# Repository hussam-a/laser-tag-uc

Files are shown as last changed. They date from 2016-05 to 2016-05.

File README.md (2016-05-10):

# laser-tag-uc
Microcontroller-based Laser Tag system

Authors:

Hussam A. El-Araby (github.com/hussam-a)

Mostafa Konsowa (github.com/konsowa)

Youssef Gaber (github.com/Gabrola)

Mennatallah Yahia

Ziad Osama

Project code and configurations are under the GNU GPL license (laser-tag-uc/LICENSE) 

# Project structure:

- Check files under folder project (laser-tag-uc/project)

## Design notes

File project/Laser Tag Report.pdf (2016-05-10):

# Laser Tag Game System: A Microcontroller-based Design

### Design and Implementation of a simple Laser Tag game system using microcontrollers that communicate with each other through laser and with a

central computer server through Wifi.

### Hussam Ashraf El-Araby Menna Yehia Mostafa Konsowa Youssef Gaber Ziad Osama

### 20th December 2015

Project Overview:
What is Laser Tag?
Laser Tag components:
Functional Requirements:
Non-functional Requirements: Market Value:
Hardware Design:
Player Unit Block Diagram
Server Block Diagram
System components communication: Microcontroller Ports:
Software Design:
System tasks:
Implementation:
Hardware Design Notes, Problems and Changes: Software Implementation:
Software Design Notes, Problems and Changes: Implemented Functional Requirements
Future Improvements:
Appendix A (Code):
Appendix B (Hardware Design):
Laser Tag Schematic Design Laser Tag Board Design
Laser Tag Bill of Materials

### Project Overview:

The following report is about our semester project for the course “Microcontroller-based System Design” with Dr. Shaalan during Fall 2015. We designed and implemented a laser tag game system. It is based on a set of microcontrollers and a central game server.

Note: Any attached pictures or files are also available in their original formats in the submission folder containing this report.

### What is Laser Tag?

Laser tag is a team or individual sport or recreational activity where players attempt to score points by tagging targets, typically with a hand-held infrared-emitting targeting device. Infrared-sensitive targets are commonly worn by each player and are sometimes integrated within the arena in which the game is played (Wikipedia).

Usually, a central server/entity exists that collects information about the game status, deaths, kills, and other game related information. However, some arenas lack a central entity and need to collect the player units after the game to calculate the scores.

In our project , we have a central computer server and several player units. The player units are microcontroller based and represent the laser shooting element (weapon) and the laser sensing element (vest). The score calculation element is the central game server (wifi connected computer).

### Laser Tag components:

Hardware view:

1. Player units: Microcontroller + LCD + Laser Sensing Element + Laser Emitting Element + Wifi
2. Central game server: Computer + Wifi
Logical view:
1. Weapon
2. Vest
3. Player LCD
4. Scoreboard and configuration server

### Functional Requirements:

The functional requirements are divided by system component (logical view)

1) Weapon:
a) Weapon shoots bullets with information about the damage the bullet incurs and the information about the shooter.
b) Weapon has current bullet count, maximum ammo, and number of magazines.
c) Weapon has shoot button, reload button and change weapon button.
d) Weapon is upgradable (according game mechanics).
2) Vest:
a) Vest senses if shot and by whom and then automatically deducts the bullet damage from health.

b) Vest detects if player is killed by bullet (health reaches zero) and by whom.
c) Vest keeps track of current health value as well as setting a maximum health value.
d) Vest contains an LED to show other players whether the player is dead or alive.
3) Player LCD:
a) LCD shows different information about weapon (as stated above)
b) LCD shows different information about health (as stated above)
4) Scoreboard and Configuration Server:
a) Scoreboard shows ranks, kills, death, and other statistics about all the players.
b) Configuration server sets game mode (Free for all vs teams)
c) Configuration server creates matches associating different players with a match being played.
d) Configuration server initializes weapons, scoreboard, and other related items at start of the match.
e) Configuration server has direct access to weapon and vest, used to upgrade the weapons, and other miscellaneous actions.
f) Configuration server ends the matches and shows final results.

### Non-functional Requirements:

### 1. Responsiveness and High Performance

a. Response times should be small to the degree the game appears instant to humans
i. Some processing can be done locally on the player unit instead of sending it to server, hence improving overall performance (less communications).

### 2. Reliability

a. Any data exchanged with the server should be verified as correct using mechanisms such as CRC.
b. Laser should be detected reliably at the specified maximum distance.
c. Ambient light should not interfere with the laser detection.
d. The game system should not loose information during the matches and the scoreboard should reflect the true performance of the players.

### 3. Scalability

a. The system should be able to handle the maximum amount of players without any apparent performance issues.
b. The server should be able to handle multiple concurrent matches if needed.

### 4. Safety

a. The laser used should not significantly harm any of the players or spectators, if accidently shined into their eyes.

### Market Value:

Laser tag is a fun game for people of a wide variety of different age groups. It would appeal to many Egyptians looking for alternative activities to do. The product, manufactured locally, would be of interest to many business owners, looking to run such an activity, but are overwhelmed by the costs of purchasing expensive equipment and building an arena. High-end laser tag equipment can cost as much as $61,800 for only 16 vests which is an extremely high price for business owners in Egypt (http://www.laser-tron.com/index.php/products/pricing-and-financing-options).

### Hardware Design:

The player unit required hardware design. Our hardware design goal was to minimise cost and yet be able to achieve the requirements.

The circuit schematic and PCD board design of the player unit are attached in the end of this document in Appendix B.

The following diagrams describe the architecture of the system.

### Player Unit Block Diagram

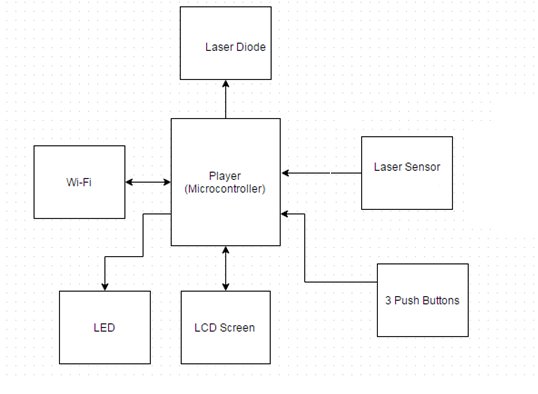
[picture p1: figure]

### Server Block Diagram

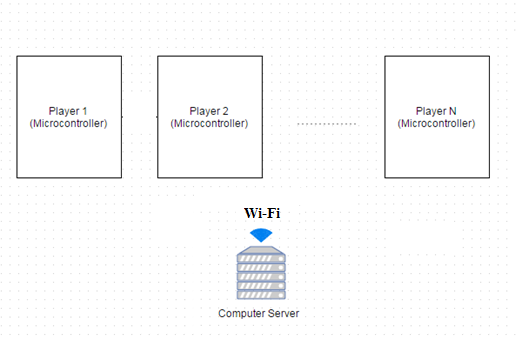
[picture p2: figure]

### System components communication:

Two communication channels exist within the system.

Player ⇔ Server

Player ⇔ Player

Player ⇔ Server Communication Protocol:

Player equipment and the server will communicate over TCP/IP.

### Microcontroller Ports:

- Laser TX: 1 I/O Pin
- Laser Sensor RX: 1 I/O Pin
- LCD Screen: 8 Data Pins, 4 Control Pins
- WiFi: 4 SPI Pins + 1 Enable Pin + 1 Interrupt Pin
- LED: 1 I/0 Pin
- 3 Buttons: 3 I/0 Pins
- Minimum I/O Pins: 24 pins

### Software Design:

The system is mainly an interrupt driven application.

### System tasks:

### 1. Gun:

N | Task | Periodic/Aperiodic | Notes
1 · The fire button is pressed · Check if player has enough ammo. · If yes: · If no: | Trigger: Action: · Sends data (player ID + bullet damage) to UART to be sent as laser pulses to hit the target · Decrease the ammo by one. · Communicate ammo change to server. (task below) · Update LCD with ammo change (task below) · Do nothing. | Aperiodic
2 · The reload button is pressed · Check if player has enough ammo. · If yes: · If no: | Trigger: Action: · Reload the ammo. · Communicate ammo change to server. (task below) · Update LCD with ammo change (task below) · Do nothing. | Aperiodic
3 · The switch weapon button is pressed · Switch to another weapon · Communicate ammo change to server (task · Update LCD with weapon change (task | Trigger: Action: below) | Aperiodic

| below)
4 · Data has been placed in UART transfer · Interrupt the TX port of the UART | Trigger: register, to be sent as laser pulses. Action: · When data signal is 0, disable the PWM. · When data signal is 1, enable the PWM | Aperiodic | PWM to be initialized to have a duty cycle of 50%. It is enabled or disabled according to data signal

### 2. Vest

| Task | Periodic/Aperiodic | Notes
1 · Laser sensor continuously receives data (light) · Demodulation of data is needed before | Description: passing the data to RX port of microcontroller | Periodic, 10KHz | Task of highest priority
2 · Decrement the health, according to bullet · Communicate health change to server (task · Update LCD with health change (task below) · If player is dead: | Trigger: Bullet information resulting from data demodulation Action: damage info. below) · Turn off their LED on their vest · Communicate who killed player to server (task below) | Aperiodic

### 3. Player LCD

1 Trigger: · Information to display on LCD changed Action: · Display is updated

Aperiodic

### 4. Server Communication

Task | Periodic/Aperiodic | Notes

1 · Server receives request from player to send · After establishing connection, server · Server has array of players, each player is a · Server updates scoreboard / other | Trigger: data to server. Action: receives data from one player and identify the player through player ID class which has private data members corresponding to the state of the player (health, weapon, ammo, score, …etc) information. | Aperiodic, happens when server receives request
2 · Server requests connection to send data · After establishing connection, server send · Player unit updates itself using this data. | Trigger: to player for example weapon upgrade Action: data to one player and identify the player through player ID | Aperiodic, happens when server send request

### Implementation:

We implemented the most important subset of the requirements for a demonstration on December 15th, 2015 (more details later on the implemented subset).
The implementation code is in Appendix A.

### Hardware Design Notes, Problems and Changes:

One main problem that faced us while designing the hardware was the choice of the laser emitting and laser sensing elements.

The laser emitting element was hard to find because we wanted to find one that:
1. Worked on 3.3V-5V.
2. Could be controlled digitally (on/off modes only).
3. Emitted a powerful enough laser to be sensed from a reasonable distance.

The laser sensing element was hard to find because:
1. Most of the light sensors on the market worked with infrared not visible light laser.
a. So it was difficult to choose both emitter and sensor of compatible frequencies.

Also it is useful to note that we implemented the project using a very small sensor. This does not reflect reality where the vest is actually has a very large surface area, but that is what we obtained to work with. Using a real vest later will require changes in the hardware design, but we assume the software would remain almost the same.

### Software Implementation:

Our implementation is based on a set of classes to manage the scoreboard, beside establishing connections with more than one player and receiving and sending packets from and to each player. We have class Player to model each player with ID, health, ammos, shots, deaths, hits, status(alive or not). We also have classes GameServerHandler inheriting from IServerHandler, class AshynchronousServer and Packet to manage establishing connection and desterilizing data from packet.
We begin by instantiating objects from GameServerHandler and AsynchronousServer classer, the object of the latter class keeps listening on a predefined port until it receives a request for connection. The server then continuously call showStatistics() and doAction() methods in Round Robin fashion.

The showStatistics() method sorts the list of players according to their score, and displays for each player Player ID, alive/dead, Kills, Deaths, Kills/Deaths Ratio, Hit Ratio, Shots, Health.

The doAction() method executes the required action depending on the status of the player (dead/alive).
We also have class BasicClient to manage client code of sending packets to the server.

### Software Design Notes, Problems and Changes:

To achieve reliability of laser sensing we intended to modulate the laser information sent by the sending end and later demodulate it at the receiving end.

Modulation/Demodulation process

The modulation/demodulation process is explained more here (http://www.schoolphysics.co.uk/age14-16/Wave%20properties/text/Modulation_and_demodulation/index.html). (http://www.schoolphysics.co.uk/age14-16/Wave%20properties/text/Modulation_and_demodulation/index.html)

Modulating the information sent (lower frequency) on a carrier signal (higher frequency) helps avoid the interference of ambient light (noise) with the laser signal.

The problem resides in the fact that the demodulation should occur all the time. The sensor cannot tell without demodulation the light entering it if a valid laser signal was sent and the contents of that signal.

The demodulation algorithm did not work on the microcontroller as we were not able to implement it sequentially within the code. It consumes most CPU cycles, blocking all the other tasks on the player unit.

It needed a separate parallel circuit, one which an FPGA can provide.

We also tried looking for hardware demodulation but due to lack of the required ICs, we just resorted to not modulating the laser signal. This affected the reliability significantly and the demonstration needed to work away from bright lights that will cause noise.

Moreover, we changed from an interrupt driven application to a round robin - state machine hybrid application. The reason for that was that we did not find that the application’s performance would suffer using the round robin method as the human reaction time covers for any delays and would not become apparent. Advantage that round robin - state machine hybrid is a simpler implementation.

### Implemented Functional Requirements

Due to limited time and pressure from the courses and upcoming finals we chose a subset to implement of the functional requirements. (check table below)

We chose the subset to showcase the most important parts of the system:
1. Component Communications (Player - Player and Player- Server)
2. Crucial Game Mechanics (Firing, Reloading, Kills, Deaths, and Scoring)

Regarding non-functional requirements, we assumed we achieved them to a sufficient level. Except for reliability due to the ambient light problem (explained above). Moreover, validating the non-functional requirements would require a larger deployment of the system and more real life use by game testers. All this was not available to us, cost wise or time wise.

Note: The index is the same as one written previously in functional requirements section.

Functional Requirement Index | Implemented? | Notes
1a | Partial | Bullet damage was not implemented, all bullets same damage.
1b | Yes
1c | Partial | Change weapon button was not implemented, as we did not do primary/secondary weapons
1d | No
2a | Partial | Related to 1a note. No specific bullet damages
2b | Yes
2c | Yes
2d | No
3a | Yes
3b | Yes
4a | Yes
4b | Partial | We only implemented a free for all mode.
4c | Yes
4d | Yes
4e | Partial | The server has the ability to initialize the players but a true direct access to all the player’s weapon and vest information is missing.
4f | Yes

### Future Improvements:

Many parts of the project may be improved.

Such as:

1. Implementing the partially and not implemented functional requirements.
2. Merge the laser emitting code with the laser sensing code (ie. unify the player unit code).
3. More deployment and testing to assert that non-functional requirements are achieved.
4. Refactor the code to make it more extensible rather than hard coded.
5. Re-evaluate whether round robin - state machine hybrid used is sufficient or is there a better method.

### Appendix A (Code):

Note: Refer to the files included in the submission.

Explanation of code arrangement:

Inside the “Demo Code” folder:

- “BasicServer” folder
- C# code that implements the game server and server functions.
- Classes used, include:
■ Event Type: class to describe all the possible game events ■ Packet: class to describe the packet sent/received
■ Player: class to describe the player
■ Other classes and functions.
- “Laser” folder
- C code that implements the laser emitting functions.
- “Sensor” folder
- C code that implements the laser sensing functions.

### Appendix B (Hardware Design):

Attached below is:

1. Eagle Schematic Design (.sch)
2. Eagle Board Design (.brd)
3. Bill of Material (BOM) (.xlsx)

### Laser Tag Schematic Design

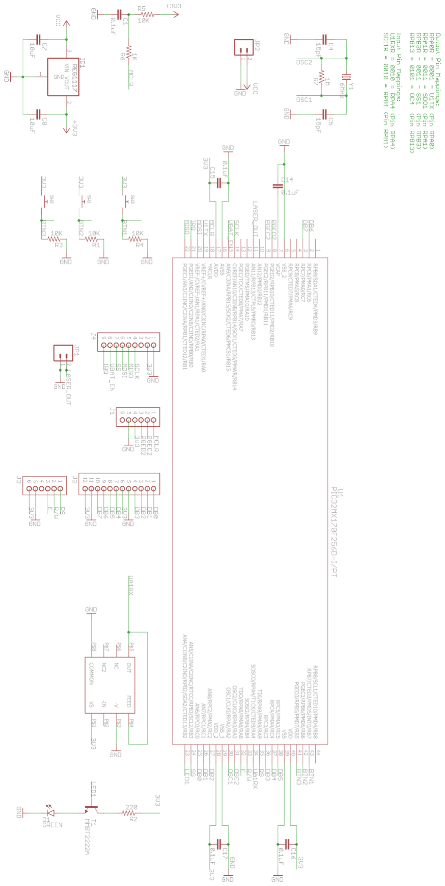
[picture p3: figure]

### Laser Tag Board Design

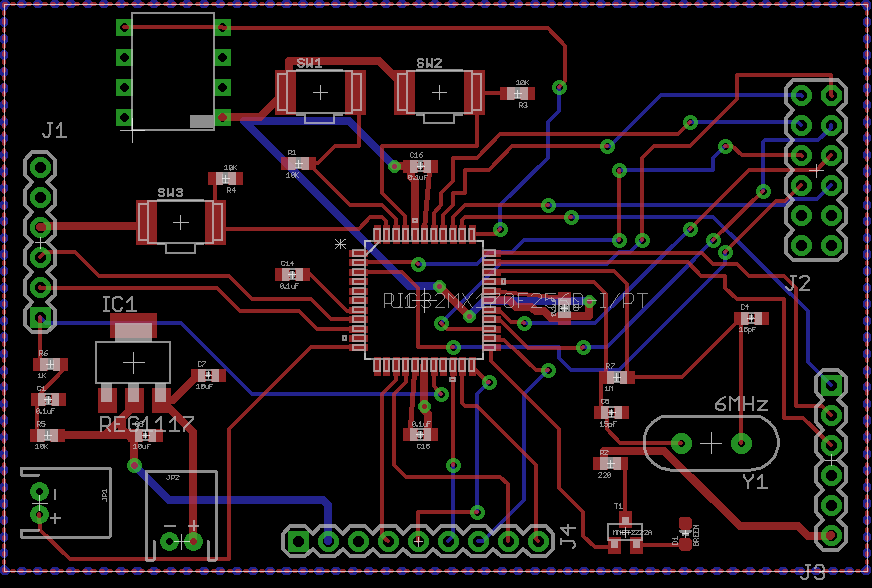
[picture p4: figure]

### Laser Tag Bill of Materials

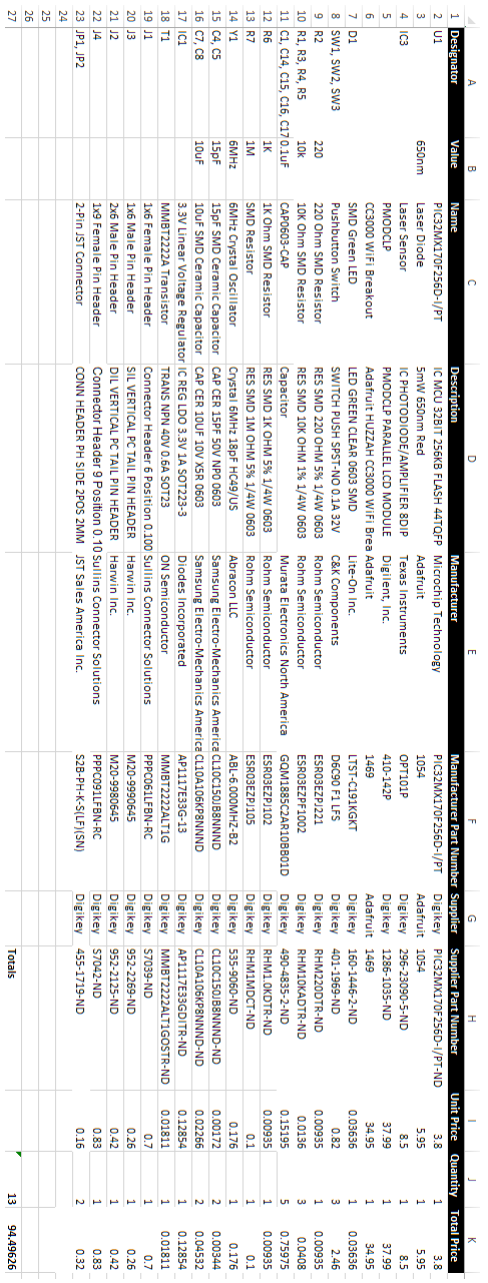
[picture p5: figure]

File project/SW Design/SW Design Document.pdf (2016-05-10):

# Microcontrollers-based system design

# S/W Design Document

# Laser Tag Project

Dr. Mohamed Shalan

4/12/2015

### Hussam El-Araby Menna Yahia Mostafa Konsowa Youssef Gaber Ziad Osama

### System components:

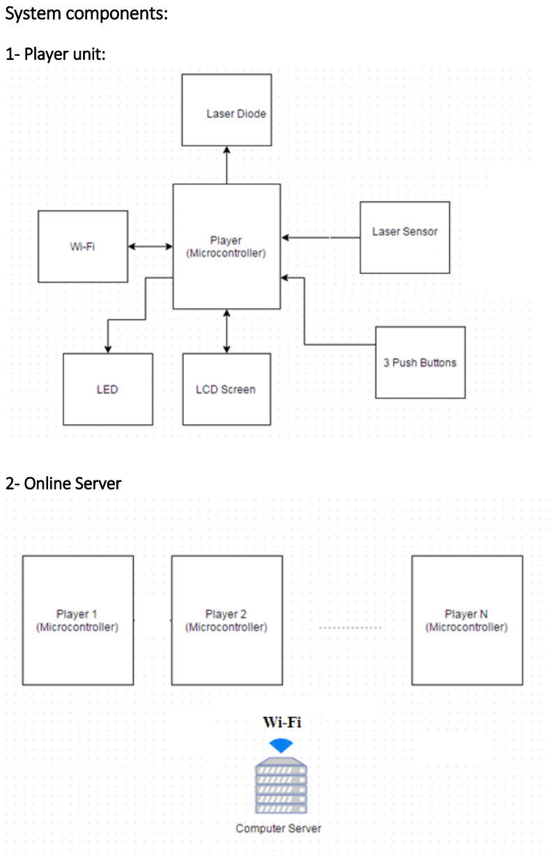
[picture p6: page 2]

### 1- Player unit:

### 2- Online Server

### Two types of communication exist in the system:

### Player – Server:

### Player – Player:

### Overview of system tasks:

### 1. Gun:

N | Task | Periodic/Aperiodic | Notes
1 | Trigger: • The fire button is pressed Action: • Check if player has enough ammo. • If yes: • Sends data (player ID + bullet damage) to UART to be sent as laser pulses to hit the target • Decrease the ammo by one. • Communicate ammo change to server. (task below) • Update LCD with ammo change (task below) • If no: • Do nothing. | Aperiodic
2 | Trigger: • The reload button is pressed Action: • Check if player has enough ammo. • If yes: • Reload the ammo. • Communicate ammo change to server. (task below) • Update LCD with ammo change (task below) • If no: • Do nothing. | Aperiodic
3 | Trigger: • The switch weapon button is pressed Action: • Switch to another weapon • Communicate ammo change to server (task below) • Update LCD with weapon change (task below) | Aperiodic
4 | Trigger: • Data has been placed in UART transfer register, to be sent as laser pulses. Action: • Interrupt the TX port of the UART | Aperiodic | PWM to be initialized to have a duty cycle of 50%. It is enabled or disabled according to data signal

- When data signal is 0, disable the PWM.
- When data signal is 1, enable the PWM

### 2. Vest

| Task | Periodic/Aperiodic | Notes
1 | Description: • Laser sensor continuously receives data (light) • Demodulation of data is needed before passing the data to RX port of microcontroller | Periodic, 10KHz | Task of highest priority
2 | Trigger: Bullet information resulting from data demodulation Action: • Decrement the health, according to bullet damage info. • Communicate health change to server (task below) • Update LCD with health change (task below) • If player is dead: • Turn off their LED on their vest • Communicate who killed player to server (task below) | Aperiodic

### 3. LCD

1 Trigger: • Information to display on LCD is changed Action: • Display is changed

Aperiodic

### 4. Server Communication

| Task | Periodic/Aperiodic | Notes
1 | Trigger: • Server receives request from player to send data to server. Action: • After establishing connection, server receives data from one player and identify the player through player ID • Server has array of players, each player is a class which has private data members | Aperiodic, happens when server receives request

| corresponding to the state of the player (health, weapon, ammo, score, …etc) • Server updates scoreboard / other information.
2 | Trigger: • Server requests connection to send data to player for example weapon upgrade Action: • After establishing connection, server send data to one player and identify the player through player ID • Player unit updates itself using this data. | Aperiodic, happens when server send request

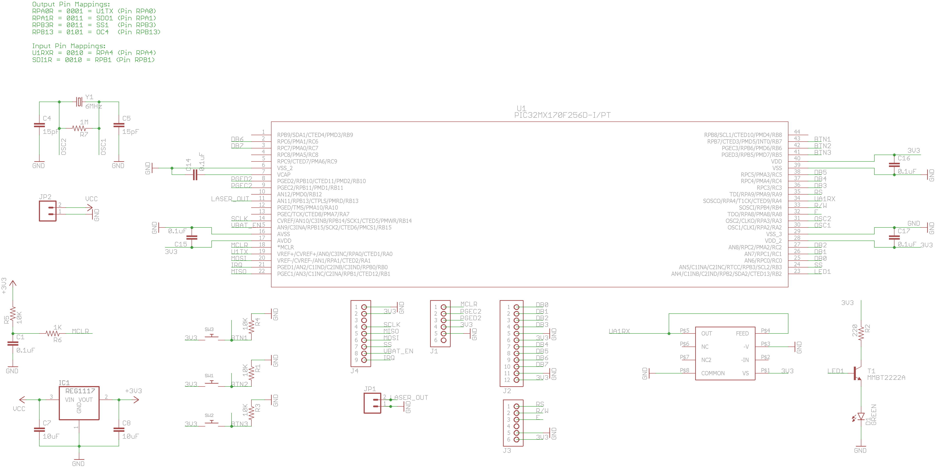
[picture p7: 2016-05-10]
project/Report Attachments/Laser Tag Schematic.png

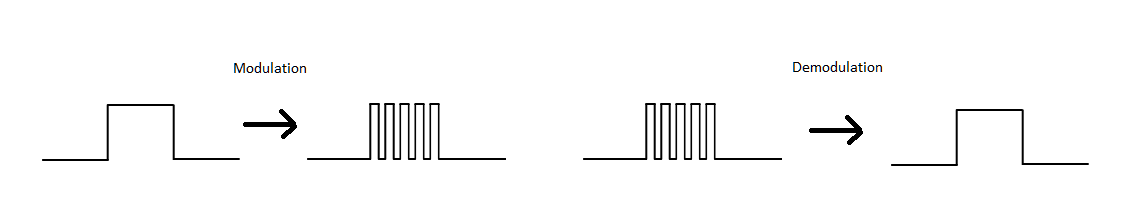
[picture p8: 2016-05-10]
project/Report Attachments/mod_demod.png

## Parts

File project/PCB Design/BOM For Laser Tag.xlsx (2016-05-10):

Designator | Value | Name | Description | Manufacturer | Manufacturer Part Number | Supplier | Supplier Part Number | Unit Price | Quantity | Total Price
U1 |  | PIC32MX170F256D-I/PT | IC MCU 32BIT 256KB FLASH 44TQFP | Microchip Technology | PIC32MX170F256D-I/PT | Digikey | PIC32MX170F256D-I/PT-ND | 3.8 | 1 | 3.8
 | 650nm | Laser Diode | 5mW 650nm Red | Adafruit | 1054 | Adafruit | 1054 | 5.95 | 1 | 5.95
IC3 |  | Laser Sensor | IC PHOTODIODE/AMPLIFIER 8DIP | Texas Instruments | OPT101P | Digikey | 296-23090-5-ND | 8.5 | 1 | 8.5
 |  | PMODCLP | PMODCLP PARALLEL LCD MODULE | Digilent, Inc. | 410-142P | Digikey | 1286-1035-ND | 37.99 | 1 | 37.99
 |  | CC3000 WiFi Breakout | Adafruit HUZZAH CC3000 WiFi Breakout | Adafruit | 1469 | Adafruit | 1469 | 34.95 | 1 | 34.95
D1 |  | SMD Green LED | LED GREEN CLEAR 0603 SMD | Lite-On Inc. | LTST-C191KGKT | Digikey | 160-1446-2-ND | 0.03636 | 1 | 0.03636
SW1, SW2, SW3 |  | Pushbutton Switch | SWITCH PUSH SPST-NO 0.1A 32V | C&K Components | D6C90 F1 LFS | Digikey | 401-1969-ND | 0.82 | 3 | 2.46
R2 | 220 | 220 Ohm SMD Resistor | RES SMD 220 OHM 5% 1/4W 0603 | Rohm Semiconductor | ESR03EZPJ221 | Digikey | RHM220DTR-ND | 0.00935 | 1 | 0.00935
R1, R3, R4, R5 | 10k | 10K Ohm SMD Resistor | RES SMD 10K OHM 1% 1/4W 0603 | Rohm Semiconductor | ESR03EZPF1002 | Digikey | RHM10KADTR-ND | 0.0136 | 3 | 0.0408
C1, C14, C15, C16, C17 | 0.1uF | CAP0603-CAP | Capacitor | Murata Electronics North America | GQM1885C2AR10BB01D | Digikey | 490-4835-2-ND | 0.15195 | 5 | 0.75975
R6 | 1K | 1K Ohm SMD Resistor | RES SMD 1K OHM 5% 1/4W 0603 | Rohm Semiconductor | ESR03EZPJ102 | Digikey | RHM1.0KDTR-ND | 0.00935 | 1 | 0.00935
R7 | 1M | SMD Resistor | RES SMD 1M OHM 5% 1/4W 0603 | Rohm Semiconductor | ESR03EZPJ105 | Digikey | RHM1MDCT-ND | 0.1 | 1 | 0.1
Y1 | 6MHz | 6MHz Crystal Oscillator | Crystal 6MHz 18pF HC49/US | Abracon LLC | ABL-6.000MHZ-B2 | Digikey | 535-9060-ND | 0.176 | 1 | 0.176
C4, C5 | 15pF | 15pF SMD Ceramic Capacitor | CAP CER 15PF 50V NP0 0603 | Samsung Electro-Mechanics America, Inc. | CL10C150JB8NNND | Digikey | CL10C150JB8NNND-ND | 0.00172 | 2 | 0.00344
C7, C8 | 10uF | 10uF SMD Ceramic Capacitor | CAP CER 10UF 10V X5R 0603 | Samsung Electro-Mechanics America, Inc. | CL10A106KP8NNND | Digikey | CL10A106KP8NNND-ND | 0.02266 | 2 | 0.04532
IC1 |  | 3.3V Linear Voltage Regulator | IC REG LDO 3.3V 1A SOT223-3 | Diodes Incorporated | AP1117E33G-13 | Digikey | AP1117E33GDITR-ND | 0.12854 | 1 | 0.12854
T1 |  | MMBT2222A Transistor | TRANS NPN 40V 0.6A SOT23 | ON Semiconductor | MMBT2222ALT1G | Digikey | MMBT2222ALT1GOSTR-ND | 0.01811 | 1 | 0.01811
J1 |  | 1x6 Female Pin Header | Connector Header 6 Position 0.100" | Sullins Connector Solutions | PPPC061LFBN-RC | Digikey | S7039-ND | 0.7 | 1 | 0.7
J3 |  | 1x6 Male Pin Header | SIL VERTICAL PC TAIL PIN HEADER | Harwin Inc. | M20-9990645 | Digikey | 952-2269-ND | 0.26 | 1 | 0.26
J2 |  | 2x6 Male Pin Header | DIL VERTICAL PC TAIL PIN HEADER | Harwin Inc. | M20-9980645 | Digikey | 952-2125-ND | 0.42 | 1 | 0.42
J4 |  | 1x9 Female Pin Header | Connector Header 9 Position 0.100" | Sullins Connector Solutions | PPPC091LFBN-RC | Digikey | S7042-ND | 0.83 | 1 | 0.83
JP1, JP2 |  | 2-Pin JST Connector | CONN HEADER PH SIDE 2POS 2MM | JST Sales America Inc. | S2B-PH-K-S(LF)(SN) | Digikey | 455-1719-ND | 0.16 | 2 | 0.32
 |  |  |  |  |  |  | Totals |  | 13 | 94.49626

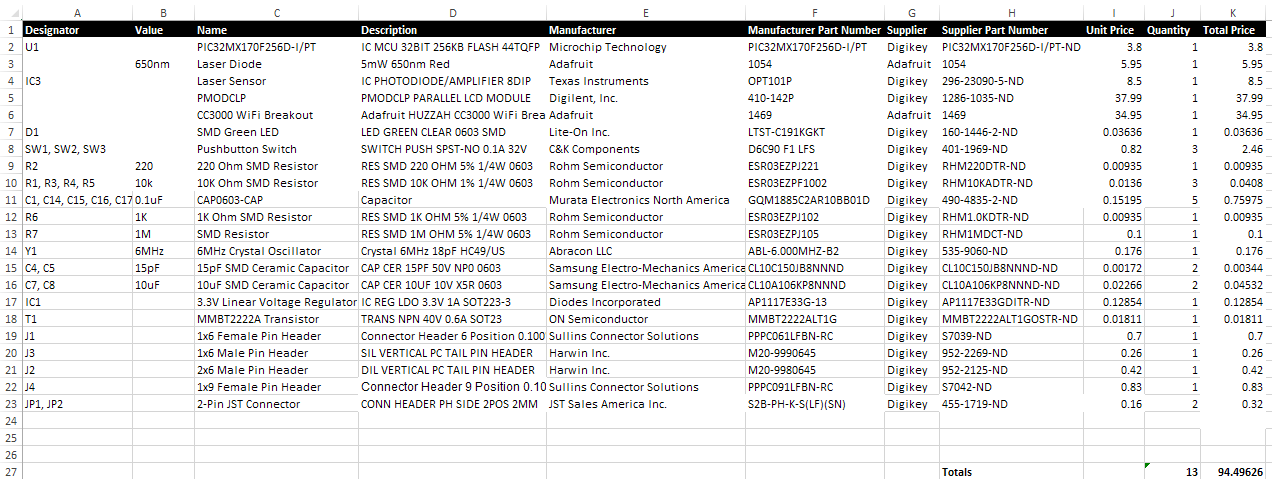
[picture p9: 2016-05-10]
project/Report Attachments/Laser Tag BOM.PNG

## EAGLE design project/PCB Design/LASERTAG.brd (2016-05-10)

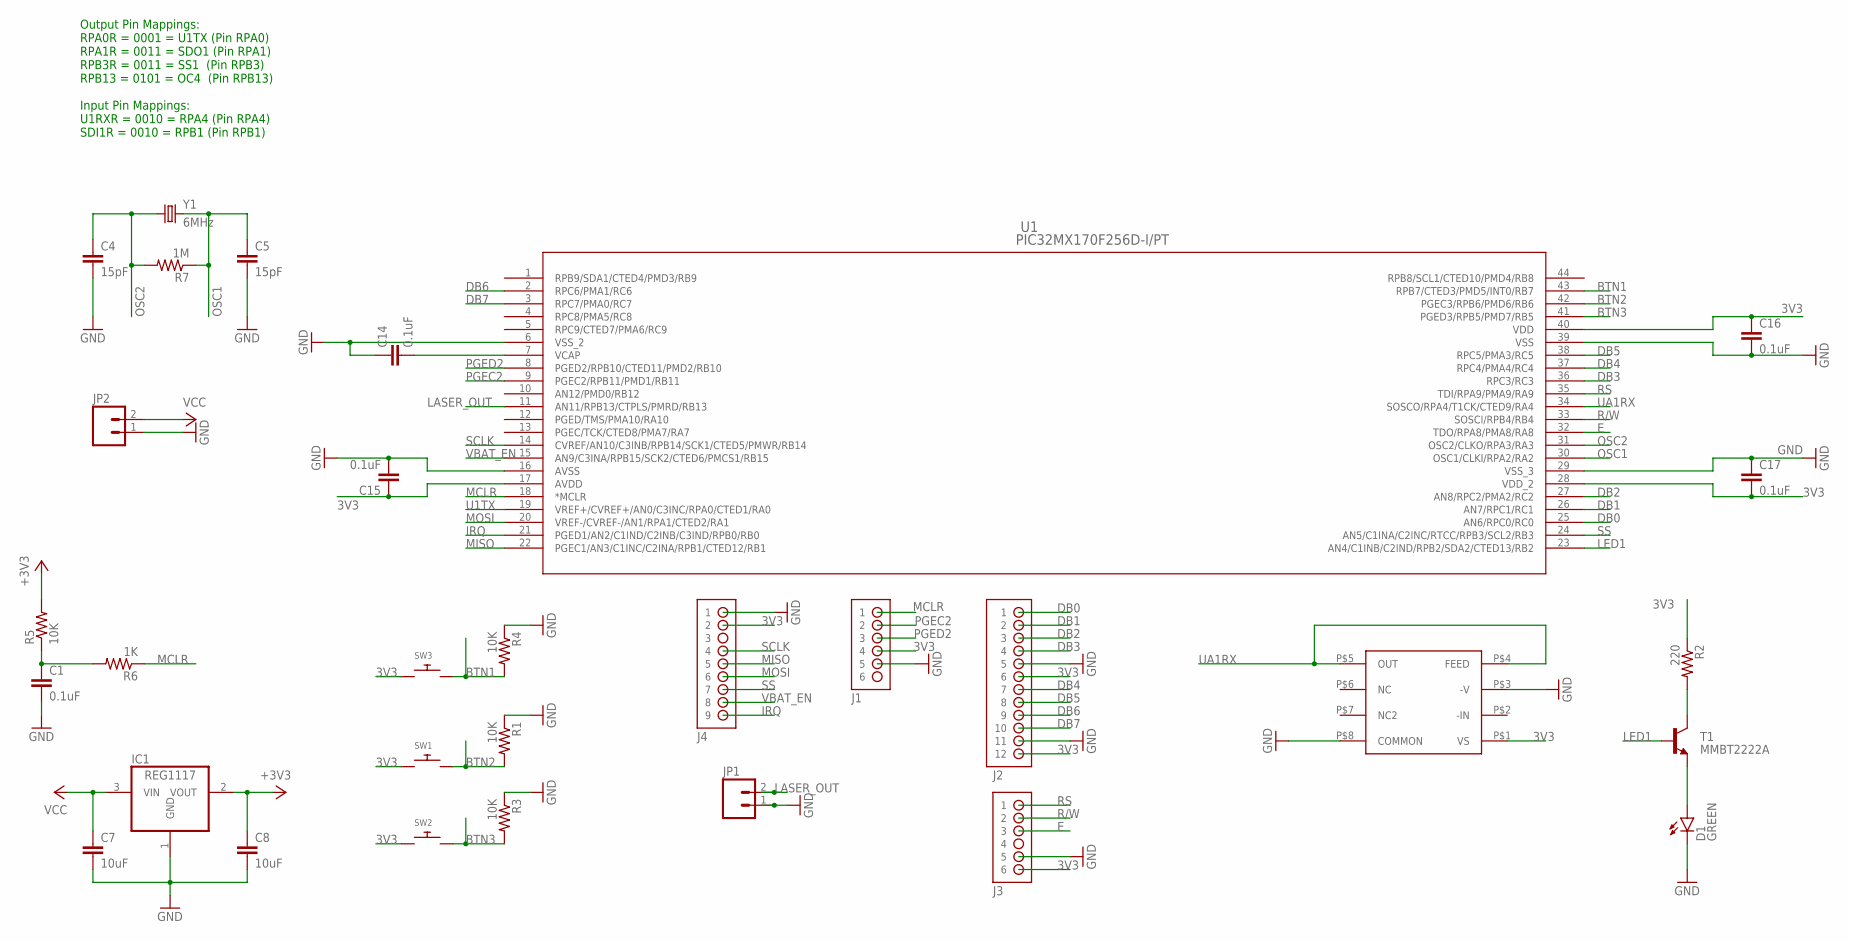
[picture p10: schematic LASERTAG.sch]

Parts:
C1, C14, C15, C16, C17: 0.1uF; 0603-CAP
C4, C5: 15pF; 0603-CAP
C7, C8: 10uF; 0603-CAP
D1: GREEN; LED-0603
IC1: REG1117; SOT223
IC3: OPT101P
J1, J3: HDR-1X6
J2: PMOD-2X6-P
J4: HDR-1X9
JP1, JP2: M02JST-PTH-2; JST-2-PTH
R1, R3, R4, R5: 10K; 0603-RES
R2: 220; 0603-RES
R6: 1K; 0603-RES
R7: 1M; 0603-RES
SW1, SW2, SW3: SWITCH_PUSHBUTTONC&K_KSS; BTN_CK_KSS
T1: MMBT2222A; SOT23
U1: PIC32MX170F256D-I/PT; TQFP44_10X10MC
Y1: 6MHz; HC49US

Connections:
3V3: C8.1, C15.1, C16.1, C17.2, IC1.2 (VOUT), IC3.P$1 (VS), J1.4, J2.6, J2.12, J3.6, J4.2, R2.1, R5.2, SW1.P$1, SW2.P$1, SW3.P$1, U1.17 (AVDD), U1.28 (VDD_2), U1.40 (VDD)
BTN1: R4.2, SW3.P$2, U1.43 (RPB7/CTED3/PMD5/INT0/RB7)
BTN2: R1.2, SW1.P$2, U1.42 (PGEC3/RPB6/PMD6/RB6)
BTN3: R3.2, SW2.P$2, U1.41 (PGED3/RPB5/PMD7/RB5)
DB0: J2.1, U1.25 (AN6/RPC0/RC0)
DB1: J2.2, U1.26 (AN7/RPC1/RC1)
DB2: J2.3, U1.27 (AN8/RPC2/PMA2/RC2)
DB3: J2.4, U1.36 (RPC3/RC3)
DB4: J2.7, U1.37 (RPC4/PMA4/RC4)
DB5: J2.8, U1.38 (RPC5/PMA3/RC5)
DB6: J2.9, U1.2 (RPC6/PMA1/RC6)
DB7: J2.10, U1.3 (RPC7/PMA0/RC7)
E: J3.3, U1.32 (TDO/RPA8/PMA8/RA8)
GND: C1.2, C4.2, C5.2, C7.2, C8.2, C14.1, C15.2, C16.2, C17.1, D1.C, IC1.1 (GND), IC3.P$3 (-V), IC3.P$8 (COMMON), J1.5, J2.5, J2.11, J3.5, J4.1, JP1.1, JP2.1, R1.1, R3.1, R4.1, U1.6 (VSS_2), U1.16 (AVSS), U1.29 (VSS_3), U1.39 (VSS)
IRQ: J4.9, U1.21 (PGED1/AN2/C1IND/C2INB/C3IND/RPB0/RB0)
LASER_OUT: JP1.2, U1.11 (AN11/RPB13/CTPLS/PMRD/RB13)
LED1: T1.1 (B), U1.23 (AN4/C1INB/C2IND/RPB2/SDA2/CTED13/RB2)
MCLR: J1.1, R6.1, U1.18 (*MCLR)
MISO: J4.5, U1.22 (PGEC1/AN3/C1INC/C2INA/RPB1/CTED12/RB1)
MOSI: J4.6, U1.20 (VREF-/CVREF-/AN1/RPA1/CTED2/RA1)
unnamed: C1.1, R5.1, R6.2
unnamed: C14.2, U1.7 (VCAP)
unnamed: R2.2, T1.3 (C)
unnamed: D1.A, T1.2 (E)
OSC1: C5.1, R7.1, U1.30 (OSC1/CLKI/RPA2/RA2), Y1.2
OSC2: C4.1, R7.2, U1.31 (OSC2/CLKO/RPA3/RA3), Y1.1
PGEC2: J1.2, U1.9 (PGEC2/RPB11/PMD1/RB11)
PGED2: J1.3, U1.8 (PGED2/RPB10/CTED11/PMD2/RB10)
R/W: J3.2, U1.33 (SOSCI/RPB4/RB4)
RS: J3.1, U1.35 (TDI/RPA9/PMA9/RA9)
SCLK: J4.4, U1.14 (CVREF/AN10/C3INB/RPB14/SCK1/CTED5/PMWR/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)
SS: J4.7, U1.24 (AN5/C1INA/C2INC/RTCC/RPB3/SCL2/RB3)
U1TX: U1.19 (VREF+/CVREF+/AN0/C3INC/RPA0/CTED1/RA0)
UA1RX: IC3.P$4 (FEED), IC3.P$5 (OUT), U1.34 (SOSCO/RPA4/T1CK/CTED9/RA4)
VBAT_EN: J4.8, U1.15 (AN9/C3INA/RPB15/SCK2/CTED6/PMCS1/RB15)
VCC: C7.1, IC1.3 (VIN), JP2.2

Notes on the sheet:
Output Pin Mappings: RPA0R = 0001 = U1TX (Pin RPA0) RPA1R = 0011 = SDO1 (Pin RPA1) RPB3R = 0011 = SS1 (Pin RPB3) RPB13 = 0101 = OC4 (Pin RPB13) Input Pin Mappings: U1RXR = 0010 = RPA4 (Pin RPA4) SDI1R = 0010 = RPB1 (Pin RPB1)

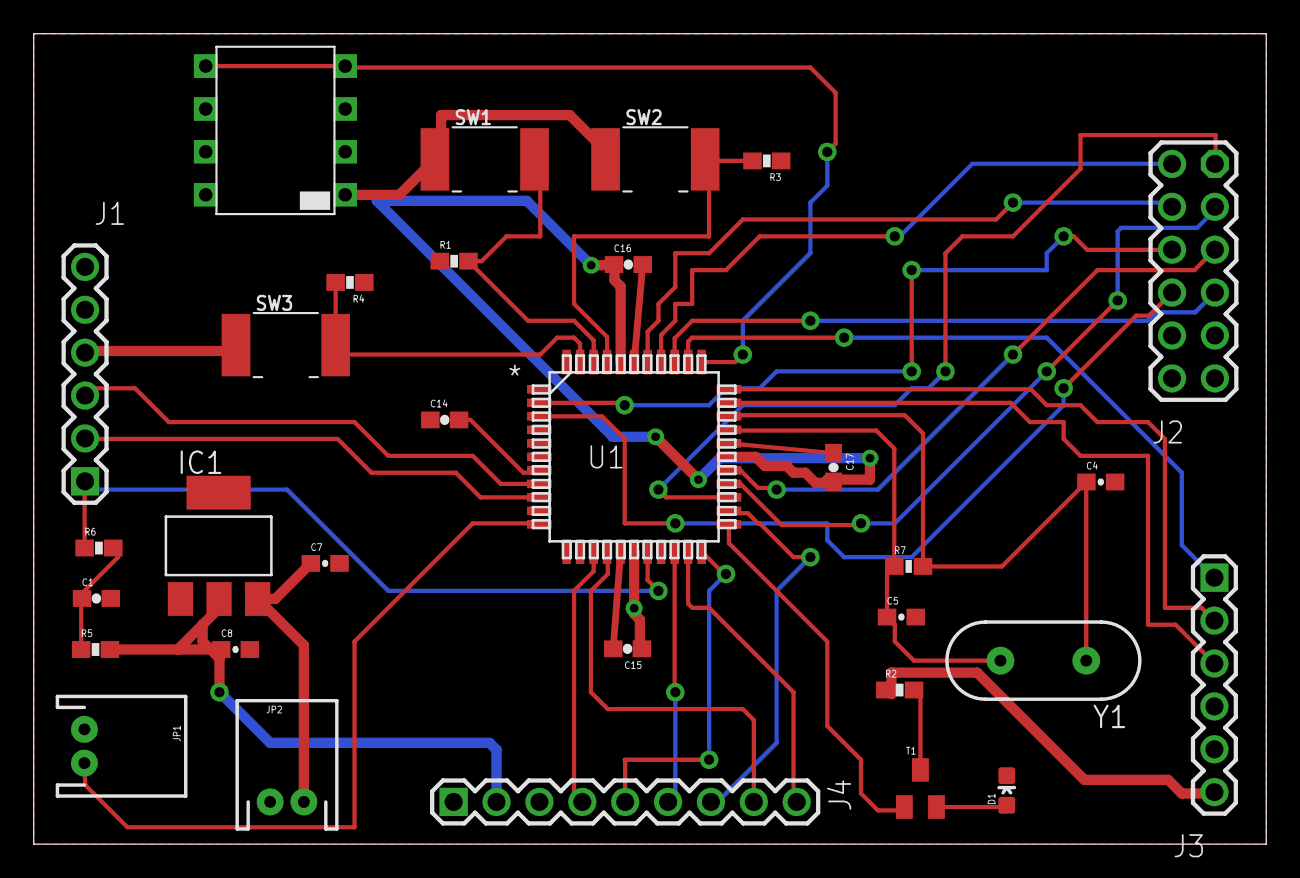
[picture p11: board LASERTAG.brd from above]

Board: 2 copper layers, 73.0 x 48.0 mm, 31 parts (0 on the bottom side), 35 nets.

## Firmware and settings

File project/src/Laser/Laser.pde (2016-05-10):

#include <LiquidCrystal.h>
#include <WiFiShieldOrPmodWiFi_G.h>
#include <DNETcK.h>
#include <DWIFIcK.h>

#include "packet.h"
#include "player.h"

#define INT2 2
#define pinINT2 7
#define INT3 3
#define pinINT3 8

LiquidCrystal lcd(26, 27, 28, 29, 30, 31, 32);

char * szIPServer = "192.168.43.151";    // server to connect to
unsigned short portServer = 52737;     // port 44300
const char * szSsid = "Wizzy";
const char * szPassPhrase = "21101994";
#define WiFiConnectMacro() DWIFIcK::connect(szSsid, szPassPhrase, &status)

typedef enum
{
    NONE = 0,
    WRITE,
    READ,
    CLOSE,
    DONE,
    WAIT
} STATE;

STATE state = WRITE;

TcpClient tcpClient;
byte rgbRead[1024];
int cbRead = 0;

byte writeBuffer[50];
int writeLength = 0;
bool pendingWrite = false;

unsigned long lastScreenRefresh = 0;

Player player;

byte ammo[8] = {
	0b00100,
	0b01110,
	0b01110,
	0b01110,
	0b01110,
	0b11111,
	0b00000,
	0b11111
};

byte heart[8] = {
	0b00000,
	0b01010,
	0b11111,
	0b11111,
	0b11111,
	0b01110,
	0b00100,
	0b00000
};

void setup() 
{
    Serial.begin(4800);
    
    randomSeed(analogRead(0));
    
    pinMode(pinINT2, INPUT);
    pinMode(pinINT3, INPUT);
    attachInterrupt(INT2, btn0Push, RISING);
    attachInterrupt(INT3, btn1Push, RISING);
    
    lcd.createChar(0, heart);
    lcd.createChar(1, ammo);
    
    lcd.begin(16, 2);
    
    lcd.print("Start");
    
    DNETcK::STATUS status;
    int conID = DWIFIcK::INVALID_CONNECTION_ID;
    
    if((conID = WiFiConnectMacro()) != DWIFIcK::INVALID_CONNECTION_ID)
    {
        lcd.setCursor(0, 0);
        lcd.print("Wifi Connected");
        state = READ;
    }
    else
    {
        lcd.setCursor(0, 0);
        lcd.print("Wifi Fail");
        state = CLOSE;
    }
    
    // use DHCP to get our IP and network addresses
    DNETcK::begin();

    // make a connection to our echo server
    tcpClient.connect(szIPServer, portServer);
} 

void sendPacket(Packet& pkt)
{
    memcpy(writeBuffer, &pkt, sizeof(pkt));
    writeLength = sizeof(pkt);
    pendingWrite = true;
}

byte laserBuffer[50];
int laserLength = 0;
unsigned long laserStart = 0;
bool pendingLaser = false;

void writeLaserData(Packet& pkt)
{
    memcpy(laserBuffer, &pkt, sizeof(pkt));
    laserLength = sizeof(pkt);
    pendingLaser = true;
    laserStart = millis();
}

void sendLaserData()
{
    if(pendingLaser)
    {
        Serial.print('L');
        Serial.write(laserBuffer, laserLength);
        
        if(millis() > laserStart + 500)
            pendingLaser = false;
    }
}

void btn0Push()
{
    if(tcpClient.isConnected() && player.canFire())
    {
        player.ammo--;
        
        Packet pkt(Packet::Shoot, player.playerID, random(1000000), 0);
        sendPacket(pkt);
        writeLaserData(pkt);
    }
}

void btn1Push()
{
    if(tcpClient.isConnected())
    {
        player.ammo = player.maxAmmo;
    }
}
 
void loop() 
{
    switch(state)
    {
       case WRITE:
            if(tcpClient.isConnected())
            {
                //tcpClient.writeStream(rgbWriteStream, cbWriteStream);
            }
            break;
            
         case WAIT:
             if(tcpClient.isConnected())
                 state = READ;
             break;
         case READ:
            if(tcpClient.isConnected())
            {
                if(pendingWrite)
                {
                    tcpClient.writeStream(writeBuffer, writeLength);
                    pendingWrite = false;
                }
                
                if((cbRead = tcpClient.available()) > 0)
                {
                    cbRead = cbRead < sizeof(rgbRead) ? cbRead : sizeof(rgbRead);
                    cbRead = tcpClient.readStream(rgbRead, cbRead);
                    
                    Packet pkt;
                    if(cbRead >= sizeof(pkt))
                    {
                        memcpy(&pkt, rgbRead, sizeof(pkt));
                        
                        if(pkt.IsValidPacket())
                        {
                            switch(pkt.Event)
                            {
                                case Packet::InitialData:
                                    player.playerID = pkt.Data1;
                                    player.maxHealth = pkt.Data2;
                                    player.maxAmmo = pkt.Data3;
                                    player.health = player.maxHealth;
                                    player.ammo = player.maxAmmo;
                                    break;
                                    
                                case Packet::Deaths:
                                    player.deaths = pkt.Data1;
                                    break;
                                    
                                case Packet::Kills:
                                    player.kills = pkt.Data1;
                                    break;
                                    
                                case Packet::IsAlive:
                                    player.isAlive = true;
                                    break;

                               case Packet::Heartbeat:
                                   Packet hpkt(Packet::Heartbeat, 0, 0, 0);
                                   sendPacket(hpkt);
                                   break;
                            }
                        }
                    }
                }
            } else {
                tcpClient.connect(szIPServer, portServer);
            }
            break;

        case CLOSE:
            tcpClient.close();
            state = DONE;
            break;

        case DONE:
        default:
            break;
    }
    
    unsigned long time = millis();
    
    if(tcpClient.isConnected() && time > lastScreenRefresh + 250)
    {
        lcd.clear();
        lcd.write((uint8_t)0);
        lcd.print("  ");
        lcd.write((uint8_t)1);
        lcd.print("  K  D  ");
        
        lcd.setCursor(0, 1);
        lcd.print(player.health, DEC);
        
        lcd.setCursor(3, 1);
        lcd.print(player.ammo, DEC);
        
        lcd.setCursor(6, 1);
        lcd.print(player.kills, DEC);
        
        lcd.setCursor(9, 1);
        lcd.print(player.deaths, DEC);
        
        lastScreenRefresh = time;
    }
    
    sendLaserData();

    // keep the stack alive each pass through the loop()
    DNETcK::periodicTasks(); 
}

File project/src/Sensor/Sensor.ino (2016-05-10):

#include <Adafruit_CC3000.h>
#include <ccspi.h>
#include <SPI.h>

#include "packet.h"
#include "player.h"

#define ADAFRUIT_CC3000_IRQ   3
#define ADAFRUIT_CC3000_VBAT  5
#define ADAFRUIT_CC3000_CS    10

Adafruit_CC3000 cc3000 = Adafruit_CC3000(ADAFRUIT_CC3000_CS, ADAFRUIT_CC3000_IRQ, ADAFRUIT_CC3000_VBAT, SPI_CLOCK_DIVIDER);

#define WLAN_SSID       "Wizzy"
#define WLAN_PASS       "21101994"
#define WLAN_SECURITY   WLAN_SEC_WPA2
uint32_t connectIp = 0xC0A82B97; //192.168.43.151
uint16_t connectPort = 52737;

typedef enum
{
    NONE = 0,
    WRITE,
    READ,
    CLOSE,
    DONE,
} STATE;

STATE state = READ;
Adafruit_CC3000_Client client;

byte rgbRead[50];
int cbRead = 0;

byte laserBuffer[20];

byte writeBuffer[50];
int writeLength = 0;
bool pendingWrite = false;

Player player;

void setup() {
  Serial.begin(4800);
  Serial.println(F("Hello, CC3000!\n")); 

  displayDriverMode();
  
  Serial.println(F("\nInitialising the CC3000 ..."));
  if (!cc3000.begin()) {
    Serial.println(F("Unable to initialise the CC3000! Check your wiring?"));
    for(;;);
  }

  uint16_t firmware = checkFirmwareVersion();
  if (firmware < 0x113) {
    Serial.println(F("Wrong firmware version!"));
    for(;;);
  } 
  
  displayMACAddress();
  
  Serial.println(F("\nDeleting old connection profiles"));
  if (!cc3000.deleteProfiles()) {
    Serial.println(F("Failed!"));
    while(1);
  }

  /* Attempt to connect to an access point */
  char *ssid = WLAN_SSID;             /* Max 32 chars */
  Serial.print(F("\nAttempting to connect to ")); Serial.println(ssid);
  
  /* NOTE: Secure connections are not available in 'Tiny' mode! */
  if (!cc3000.connectToAP(WLAN_SSID, WLAN_PASS, WLAN_SECURITY)) {
    Serial.println(F("Failed!"));
    while(1);
  }
   
  Serial.println(F("Connected!"));
  
  /* Wait for DHCP to complete */
  Serial.println(F("Request DHCP"));
  while (!cc3000.checkDHCP()) {
    delay(100); // ToDo: Insert a DHCP timeout!
  }

  /* Display the IP address DNS, Gateway, etc. */  
  while (!displayConnectionDetails()) {
    delay(1000);
  }

  client = cc3000.connectTCP(connectIp, connectPort);
}

void sendPacket(Packet& pkt)
{
    memcpy(writeBuffer, &pkt, sizeof(pkt));
    client.write(writeBuffer, sizeof(pkt));
}

void handleData(byte* buffer, int length)
{
  Packet pkt;
  
  if(length < sizeof(pkt))
    return;
  memcpy(&pkt, rgbRead, sizeof(pkt));

  if(pkt.IsValidPacket())
  {
      switch(pkt.Event)
      {
          case Packet::InitialData:
              player.playerID = pkt.Data1;
              player.maxHealth = pkt.Data2;
              player.maxAmmo = pkt.Data3;
              player.health = player.maxHealth;
              player.ammo = player.maxAmmo;

              Serial.print("Player ID: ");
              Serial.println(player.playerID);
              break;
              
          case Packet::Deaths:
              player.deaths = pkt.Data1;

              Serial.print("Deaths: ");
              Serial.println(player.deaths);
              break;
              
          case Packet::Kills:
              player.kills = pkt.Data1;

              Serial.print("Kills: ");
              Serial.println(player.kills);
              break;
              
          case Packet::IsAlive:
              player.isAlive = true;
              player.health = player.maxHealth;

              Serial.print("Revived!");
              break;

          case Packet::Heartbeat:
              Packet hpkt(Packet::Heartbeat, 0, 0, 0);
              sendPacket(hpkt);
              break;
      }
  }
}

int32_t lastDecrease = 0;

void handleDataLaser(byte* buffer, int length)
{
  Packet pkt;
  
  if(length < sizeof(pkt))
    return;
    
  memcpy(&pkt, buffer, sizeof(pkt));

  if(pkt.IsValidPacket())
  {
      Serial.print("Event ID: ");
      Serial.println(pkt.Event);
      
      switch(pkt.Event)
      {
        case Packet::Shoot:
          if(pkt.Data2 == lastDecrease)
            break;

          lastDecrease = pkt.Data2;
          
          if(player.isAlive)
          {
            player.decreaseHealth(1);
            
            Packet pkt2(Packet::Health, player.health, pkt.Data1, 0);
            sendPacket(pkt2);
          }
          break;
      }
  }
  else
  {
    Serial.println("Invalid laser packet");
  }
}

/**************************************************************************/
/*!
    @brief  Displays the driver mode (tiny of normal), and the buffer
            size if tiny mode is not being used

    @note   The buffer size and driver mode are defined in cc3000_common.h
*/
/**************************************************************************/
void displayDriverMode(void)
{
  #ifdef CC3000_TINY_DRIVER
    Serial.println(F("CC3000 is configure in 'Tiny' mode"));
  #else
    Serial.print(F("RX Buffer : "));
    Serial.print(CC3000_RX_BUFFER_SIZE);
    Serial.println(F(" bytes"));
    Serial.print(F("TX Buffer : "));
    Serial.print(CC3000_TX_BUFFER_SIZE);
    Serial.println(F(" bytes"));
  #endif
}

/**************************************************************************/
/*!
    @brief  Tries to read the CC3000's internal firmware patch ID
*/
/**************************************************************************/
uint16_t checkFirmwareVersion(void)
{
  uint8_t major, minor;
  uint16_t version;
  
#ifndef CC3000_TINY_DRIVER  
  if(!cc3000.getFirmwareVersion(&major, &minor))
  {
    Serial.println(F("Unable to retrieve the firmware version!\r\n"));
    version = 0;
  }
  else
  {
    Serial.print(F("Firmware V. : "));
    Serial.print(major); Serial.print(F(".")); Serial.println(minor);
    version = major; version <<= 8; version |= minor;
  }
#endif
  return version;
}

/**************************************************************************/
/*!
    @brief  Tries to read the 6-byte MAC address of the CC3000 module
*/
/**************************************************************************/
void displayMACAddress(void)
{
  uint8_t macAddress[6];
  
  if(!cc3000.getMacAddress(macAddress))
  {
    Serial.println(F("Unable to retrieve MAC Address!\r\n"));
  }
  else
  {
    Serial.print(F("MAC Address : "));
    cc3000.printHex((byte*)&macAddress, 6);
  }
}
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

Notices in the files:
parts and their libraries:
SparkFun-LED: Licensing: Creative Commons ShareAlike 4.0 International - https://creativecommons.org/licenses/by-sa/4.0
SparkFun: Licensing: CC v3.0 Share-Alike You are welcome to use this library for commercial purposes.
